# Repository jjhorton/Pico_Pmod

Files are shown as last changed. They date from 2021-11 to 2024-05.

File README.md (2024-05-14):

The aim of this repo is to have a PCB on which I was able to mount a standard
[Raspberry Pi Pico](https://www.raspberrypi.org/products/raspberry-pi-pico/) and have an extended duel PMod Connector. This would allow me to connect up the Raspberry Pi Pico upto a range of PMod Boards that I already own, as well as to connect it upto some of the FPGA boards that I already own though there PMod connector.

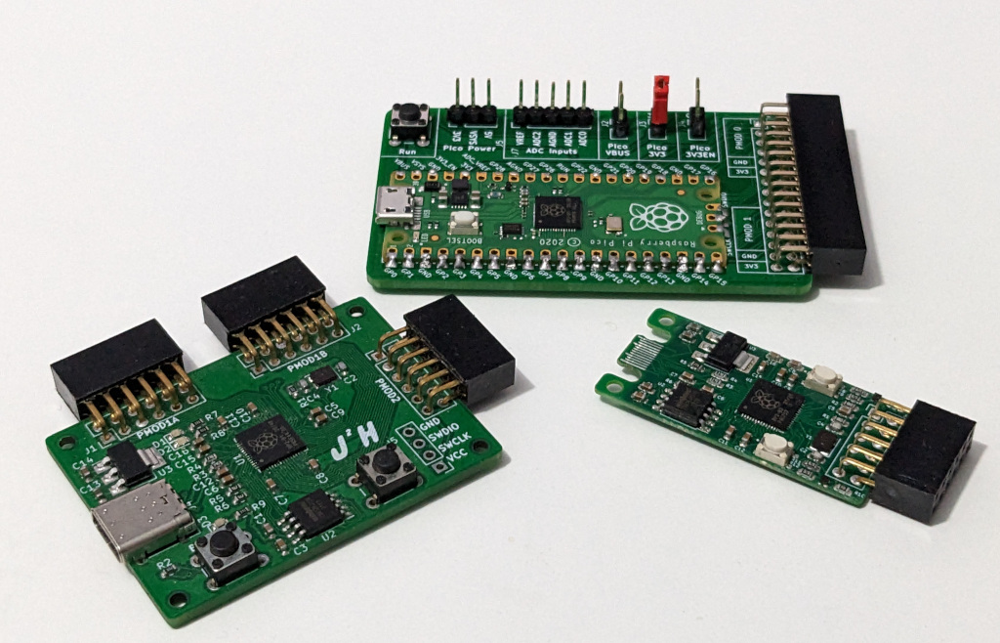
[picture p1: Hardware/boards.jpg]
All three PMod Boards


# Hardware

| Board | Build Status | Description |
| --- | --- | --- |
| [Pico PMod](https://kicanvas.org/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) |  | Raspberry Pi Pico Based PMod Breakout Board |
| [RP2040 PMod](https://kicanvas.org/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) |  | A PMod Board based on the RP2040 Chip |
| [RP2040 Mini PMod](https://kicanvas.org/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) |  | A mini Board with a single PMod connector and SD card reader |

For working with the pre existing PMod Boards I've made a PMod Host board,
this hosts the accessories such as an [Seven Segment display]() or
[PMOD buttons](). This allows me to work with boards I already have For
my FPGA development boards, and connect them up to the Pico.

The second board is designed to use the RP2040 chip directly, and create a small form factor PMod Board, this will use the RP2040 reference design, with a USB-C (2.0) Port, and 3 PMod Connectors that allow for PMod Devices to be connected up to the RP2040.

# Software

These are some examples that I have written to make use of the Host board with
my existing PMod accessories that I have around, these are two examples from Mouser which can be purchased, they are a [Seven Segment Display](https://www.mouser.co.uk/ProductDetail/1BitSquared/CS-ICEBREAKER-08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) and a [8 way switch](https://www.mouser.co.uk/ProductDetail/1BitSquared/CS-ICEBREAKER-07?qs=Cb2nCFKsA8ouK5JTufn3Bg%3D%3D). These simple examples can be found in the Software Folder, are written in `C` and require the Pico SDK to be able to build them.

These Software examples currently target only the board Pico Pmod Board, pins need to be changed for them to work with the RP2040 Board.

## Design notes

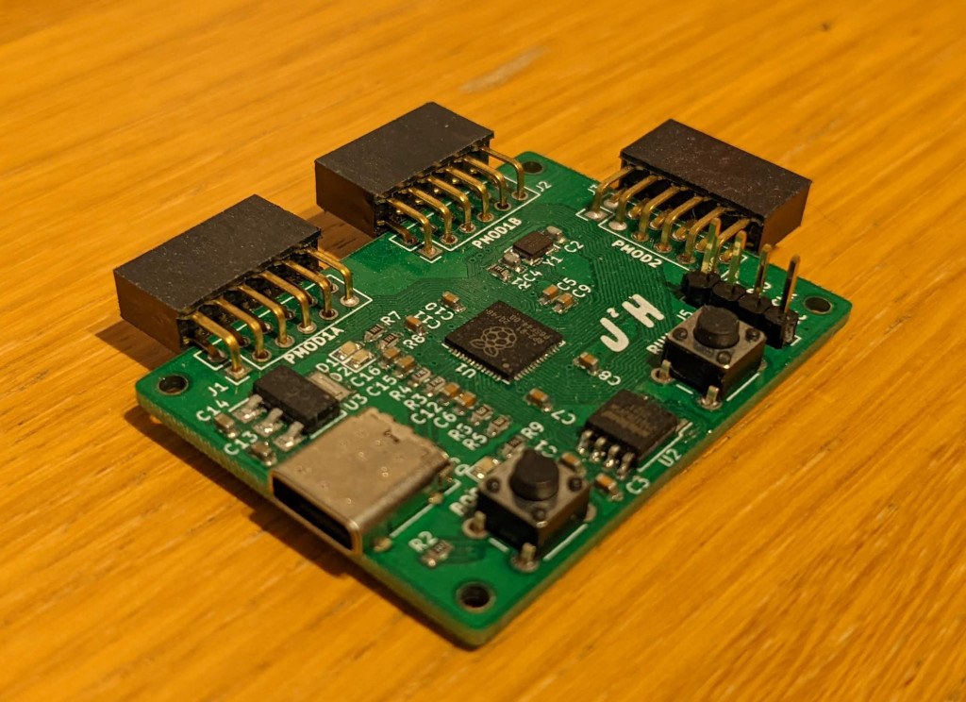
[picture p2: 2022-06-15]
Hardware/RP2040_PMod/board.jpg

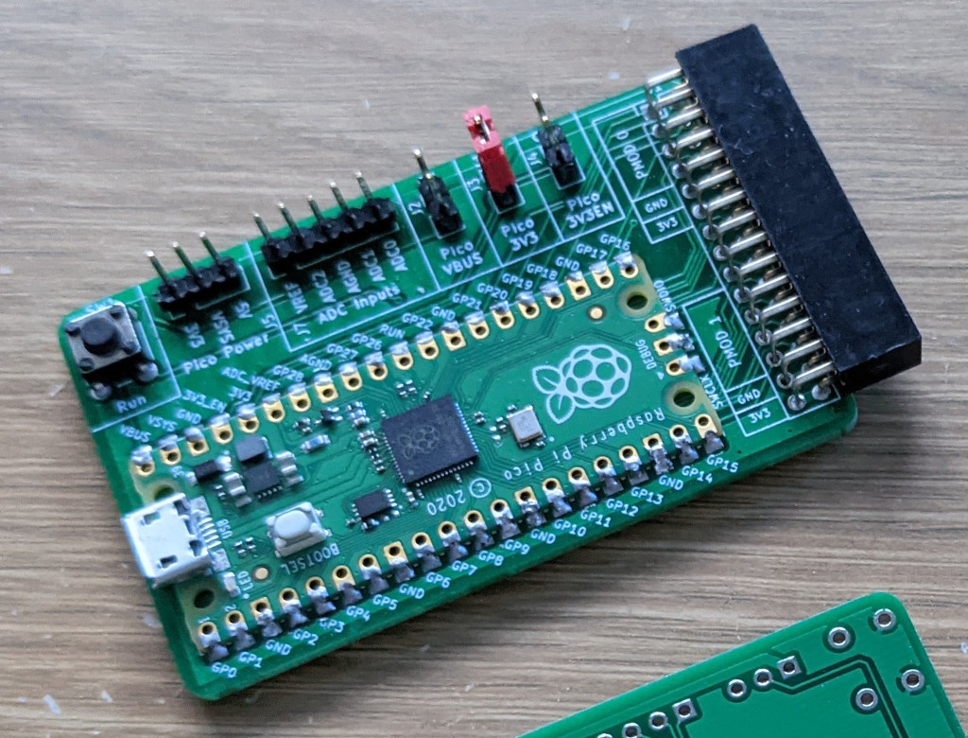
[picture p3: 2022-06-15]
Hardware/Pico_PMod/board.jpg

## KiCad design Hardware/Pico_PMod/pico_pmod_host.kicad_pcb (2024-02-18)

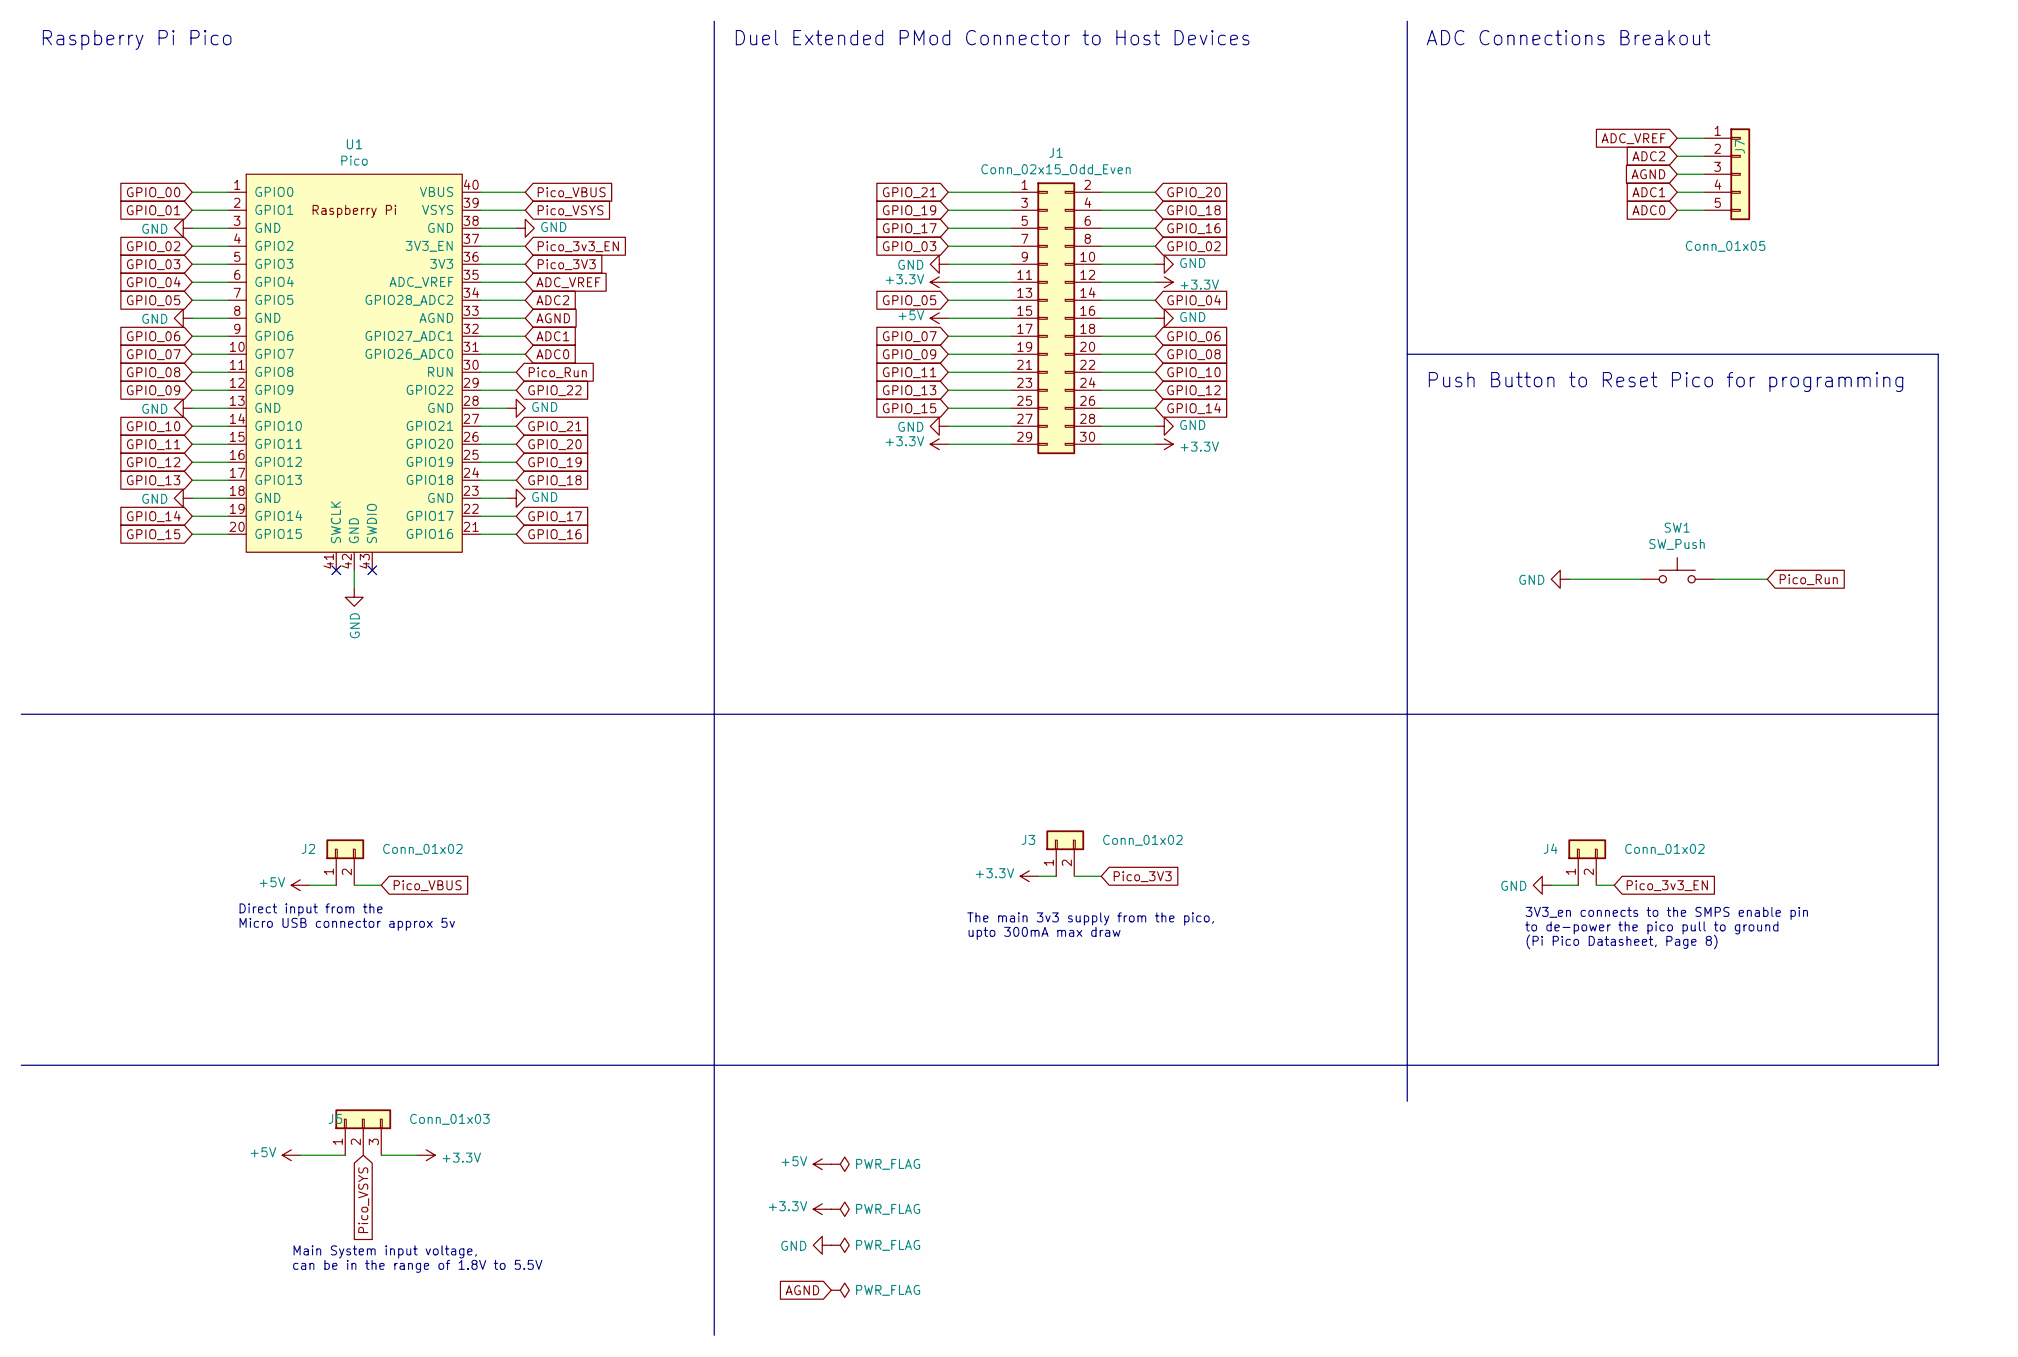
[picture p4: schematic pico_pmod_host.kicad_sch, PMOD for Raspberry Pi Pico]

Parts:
J1: Conn_02x15_Odd_Even; PinHeader_2x15_P2.54mm_Vertical
J2, J3, J4: Conn_01x02; PinHeader_1x02_P2.54mm_Vertical
J5: Conn_01x03; PinHeader_1x03_P2.54mm_Vertical
J7: Conn_01x05; PinHeader_1x05_P2.54mm_Vertical
SW1: SW_Push; SW_PUSH_6mm_H4.3mm
U1: Pico; RPi_Pico_SMD_TH

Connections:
+3V3: J1.11, J1.12, J1.29, J1.30, J3.1, J5.3
+5V: J1.15, J2.1, J5.1
ADC0: J7.5, U1.31 (GPIO26_ADC0)
ADC1: J7.4, U1.32 (GPIO27_ADC1)
ADC2: J7.2, U1.34 (GPIO28_ADC2)
ADC_VREF: J7.1, U1.35 (ADC_VREF)
AGND: J7.3, U1.33 (AGND)
GND: J1.9, J1.10, J1.16, J1.27, J1.28, J4.1, SW1.1, U1.3 (GND), U1.8 (GND), U1.13 (GND), U1.18 (GND), U1.23 (GND), U1.28 (GND), U1.38 (GND), U1.42 (GND)
GPIO_00: U1.1 (GPIO0)
GPIO_01: U1.2 (GPIO1)
GPIO_02: J1.8, U1.4 (GPIO2)
GPIO_03: J1.7, U1.5 (GPIO3)
GPIO_04: J1.14, U1.6 (GPIO4)
GPIO_05: J1.13, U1.7 (GPIO5)
GPIO_06: J1.18, U1.9 (GPIO6)
GPIO_07: J1.17, U1.10 (GPIO7)
GPIO_08: J1.20, U1.11 (GPIO8)
GPIO_09: J1.19, U1.12 (GPIO9)
GPIO_10: J1.22, U1.14 (GPIO10)
GPIO_11: J1.21, U1.15 (GPIO11)
GPIO_12: J1.24, U1.16 (GPIO12)
GPIO_13: J1.23, U1.17 (GPIO13)
GPIO_14: J1.26, U1.19 (GPIO14)
GPIO_15: J1.25, U1.20 (GPIO15)
GPIO_16: J1.6, U1.21 (GPIO16)
GPIO_17: J1.5, U1.22 (GPIO17)
GPIO_18: J1.4, U1.24 (GPIO18)
GPIO_19: J1.3, U1.25 (GPIO19)
GPIO_20: J1.2, U1.26 (GPIO20)
GPIO_21: J1.1, U1.27 (GPIO21)
GPIO_22: U1.29 (GPIO22)
Pico_3V3: J3.2, U1.36 (3V3)
Pico_3v3_EN: J4.2, U1.37 (3V3_EN)
Pico_Run: SW1.2, U1.30 (RUN)
Pico_VBUS: J2.2, U1.40 (VBUS)
Pico_VSYS: J5.2, U1.39 (VSYS)

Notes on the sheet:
Duel Extended PMod Connector to Host Devices
Main System input voltage, can be in the range of 1.8V to 5.5V
3V3_en connects to the SMPS enable pin to de-power the pico pull to ground (Pi Pico Datasheet, Page 8)
The main 3v3 supply from the pico, upto 300mA max draw
Push Button to Reset Pico for programming
ADC Connections Breakout
Direct input from the Micro USB connector approx 5v
Raspberry Pi Pico

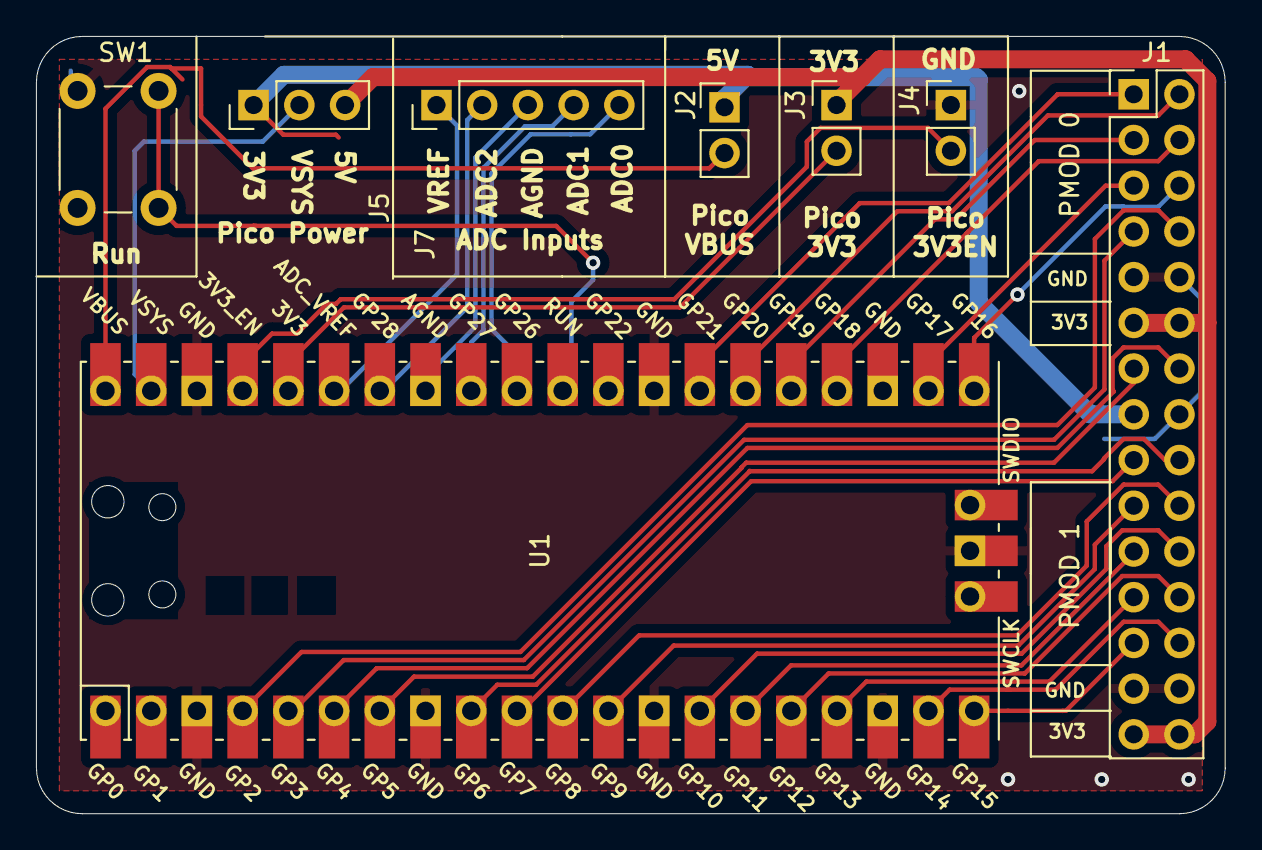
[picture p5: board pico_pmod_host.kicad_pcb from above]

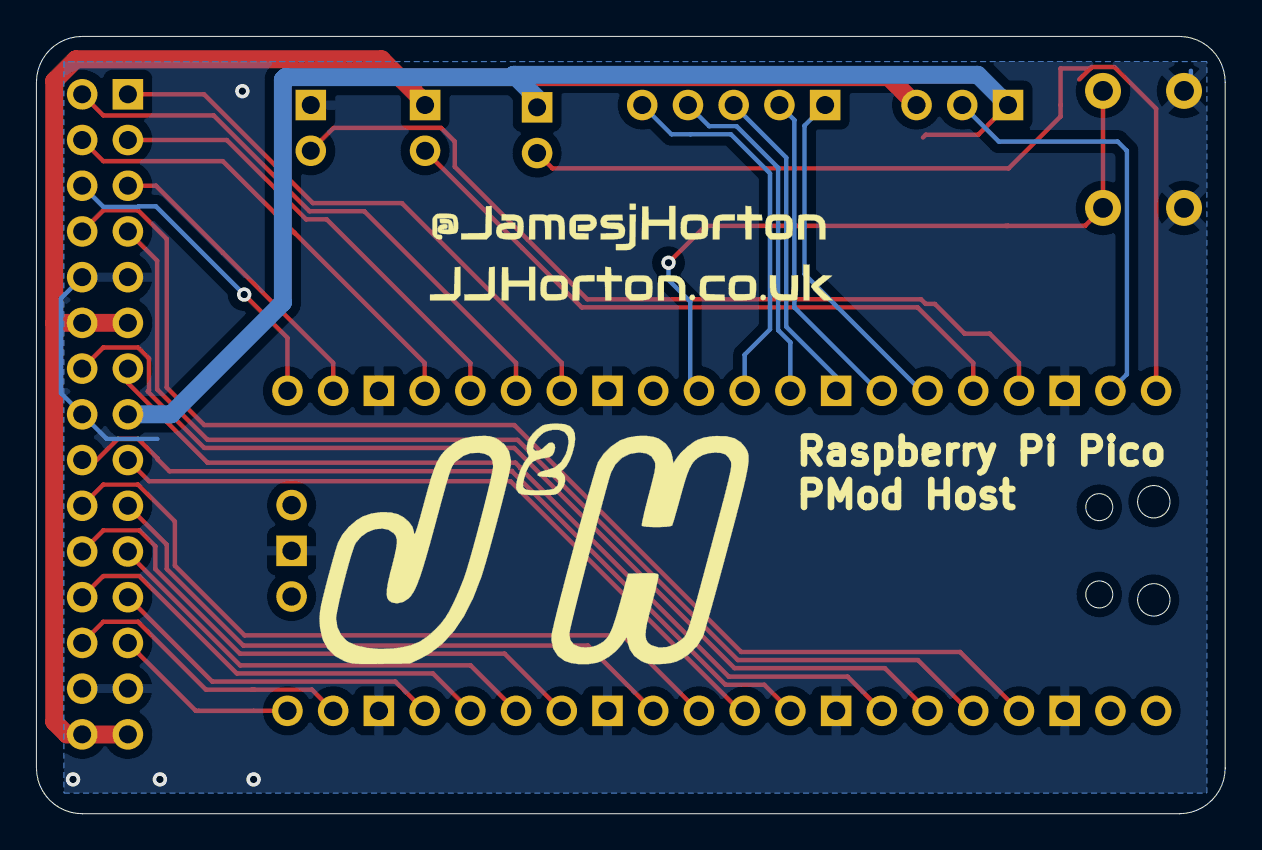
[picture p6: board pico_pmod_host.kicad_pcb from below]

Board: 2 copper layers, 66.0 x 43.2 mm, 10 parts (2 on the bottom side), 33 nets.

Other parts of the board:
Logo1: LOGO; Untitled
Logo2: LOGO; ContactDetails_small

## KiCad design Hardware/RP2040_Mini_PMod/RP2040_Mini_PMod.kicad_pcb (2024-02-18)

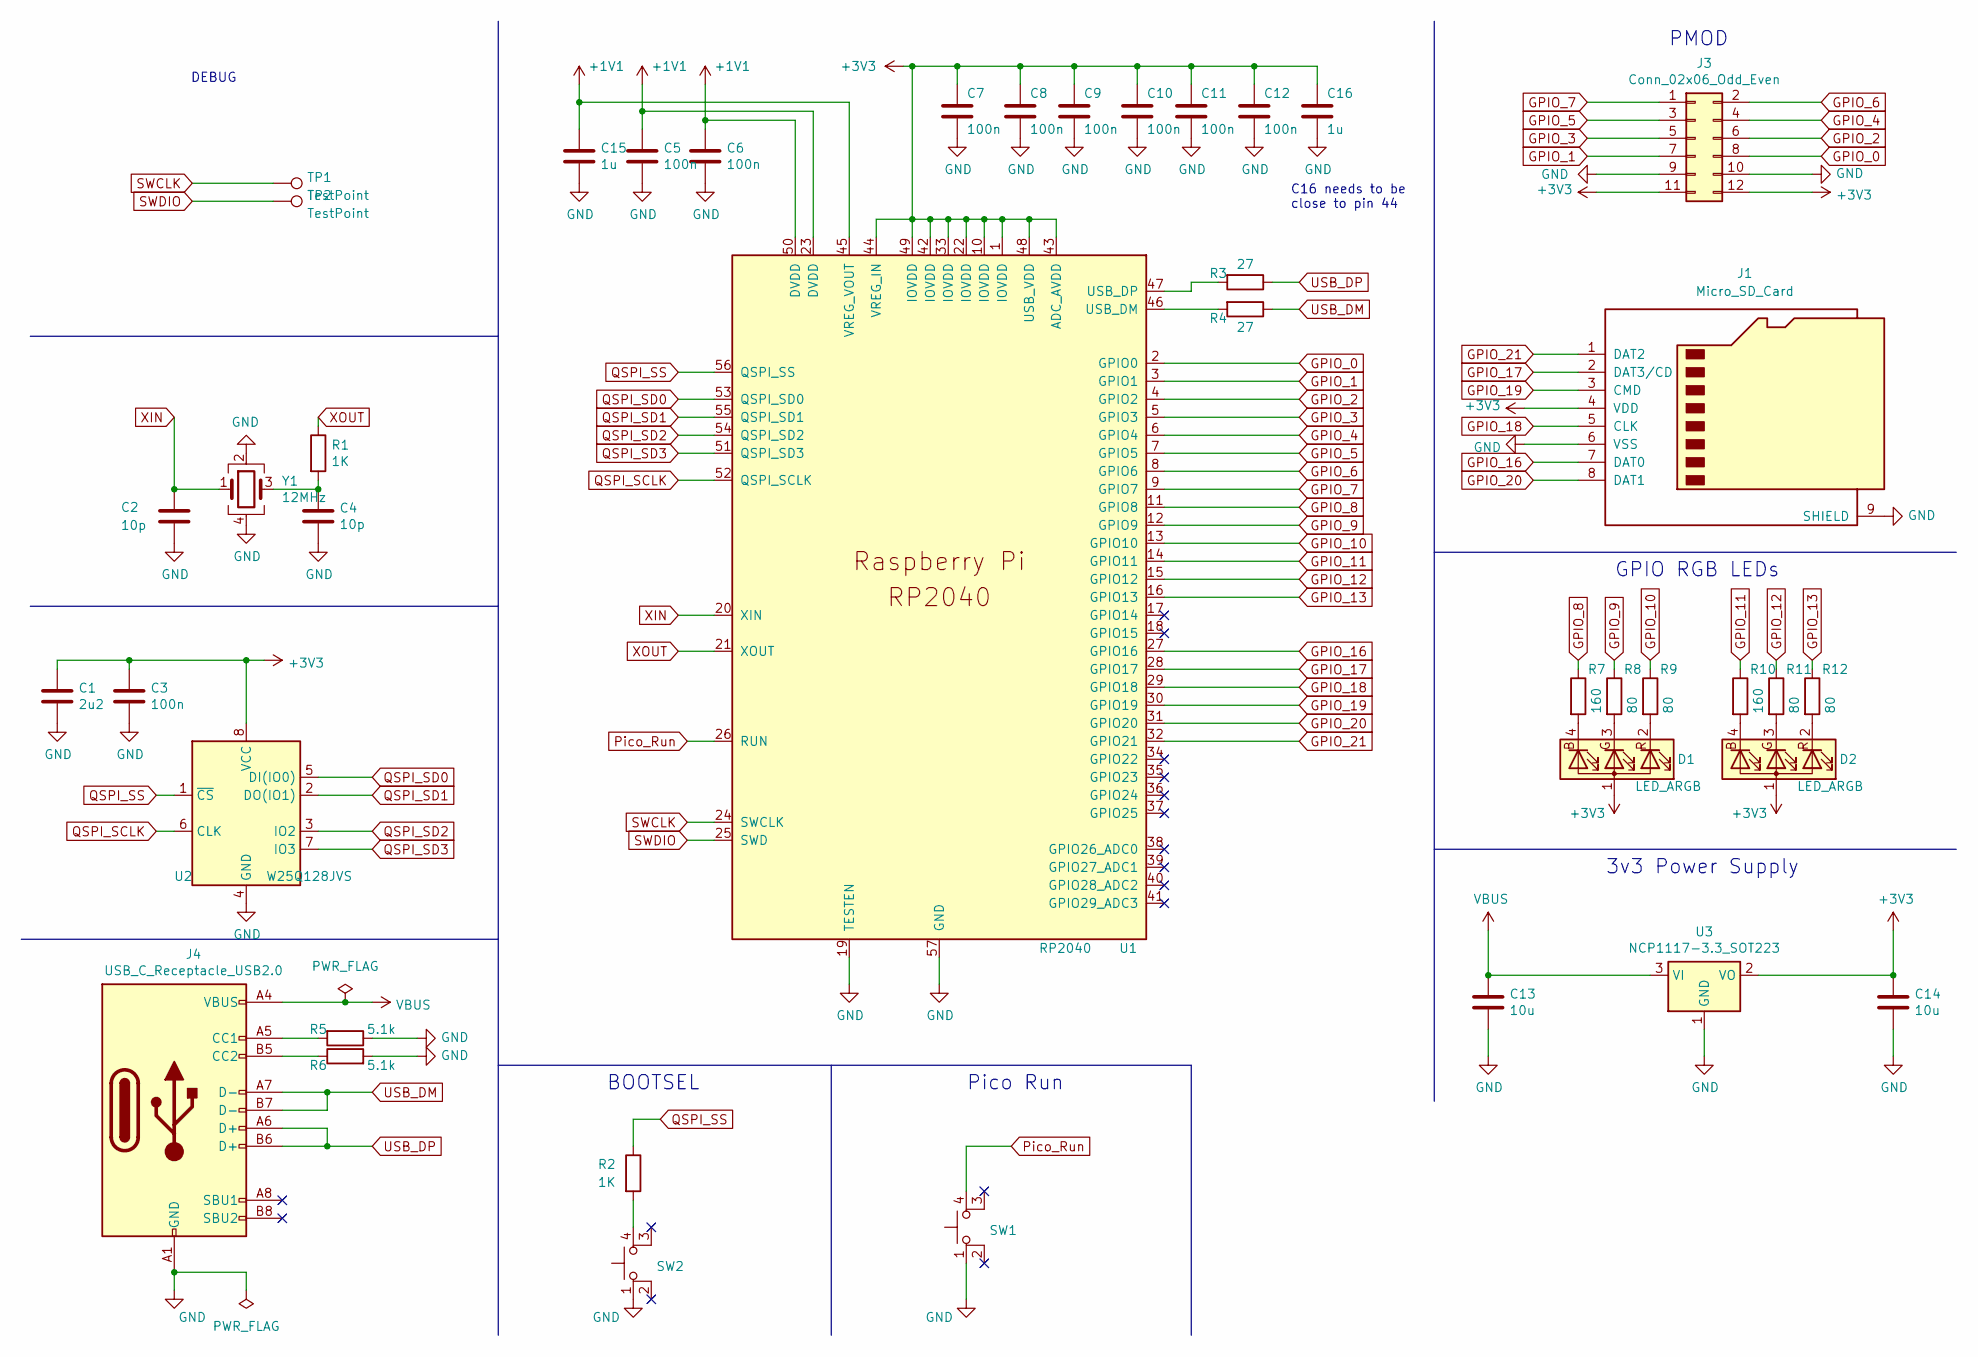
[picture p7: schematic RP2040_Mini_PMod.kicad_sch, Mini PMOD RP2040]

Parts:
C1: 2u2; C_0603_1608Metric
C2, C4: 10p; C_0603_1608Metric
C3, C5, C6, C7, C8, C9, C10, C11, C12: 100n; C_0603_1608Metric
C13, C14: 10u; C_0603_1608Metric
C15, C16: 1u; C_0603_1608Metric
D1, D2: LED_ARGB; SX-0402-RGB
J1: Micro_SD_Card; 105162-0001
J3: Conn_02x06_Odd_Even; PinHeader_2x06_P2.54mm_Vertical
J4: USB_C_Receptacle_USB2.0; USB-C-PCB
R1, R2: 1K; R_0603_1608Metric
R3, R4: 27; R_0603_1608Metric
R5, R6: 5.1k; R_0603_1608Metric
R7, R10: 160; R_0603_1608Metric
R8, R9, R11, R12: 80; R_0603_1608Metric
SW1, SW2: PTS815 SJK 250 SMTR LFS; PTS815SJK250SMTRLFS
TP1, TP2: TestPoint; TestPoint_Pad_D1.5mm
U1: RP2040; RP2040-QFN-56
U2: W25Q128JVS; SOIC-8_5.23x5.23mm_P1.27mm
U3: NCP1117-3.3_SOT223; SOT-223-3_TabPin2
Y1: 12MHz; Crystal_SMD_SeikoEpson_FA238-4Pin_3.2x2.5mm

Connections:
+1V1: C5.1, C6.1, C15.1, U1.23 (DVDD), U1.45 (VREG_VOUT), U1.50 (DVDD)
+3V3: C1.1, C3.1, C7.1, C8.1, C9.1, C10.1, C11.1, C12.1, C14.1, C16.1, D1.1 (A), D2.1 (A), J1.4 (VDD), J3.11, J3.12, U1.1 (IOVDD), U1.10 (IOVDD), U1.22 (IOVDD), U1.33 (IOVDD), U1.42 (IOVDD), U1.43 (ADC_AVDD), U1.44 (VREG_IN), U1.48 (USB_VDD), U1.49 (IOVDD), U2.8 (VCC), U3.2 (VO)
GND: C1.2, C2.2, C3.2, C4.2, C5.2, C6.2, C7.2, C8.2, C9.2, C10.2, C11.2, C12.2, C13.2, C14.2, C15.2, C16.2, J1.6 (VSS), J1.9 (SHIELD), J3.9, J3.10, J4.A1 (GND), J4.A12 (GND), J4.B1 (GND), J4.B12 (GND), R5.1, R6.2, SW1.1, SW2.1, U1.19 (TESTEN), U1.57 (GND), U2.4 (GND), U3.1 (GND), Y1.2, Y1.4
GPIO_0: J3.8, U1.2 (GPIO0)
GPIO_1: J3.7, U1.3 (GPIO1)
GPIO_2: J3.6, U1.4 (GPIO2)
GPIO_3: J3.5, U1.5 (GPIO3)
GPIO_4: J3.4, U1.6 (GPIO4)
GPIO_5: J3.3, U1.7 (GPIO5)
GPIO_6: J3.2, U1.8 (GPIO6)
GPIO_7: J3.1, U1.9 (GPIO7)
GPIO_8: R7.1, U1.11 (GPIO8)
GPIO_9: R8.1, U1.12 (GPIO9)
GPIO_10: R9.1, U1.13 (GPIO10)
GPIO_11: R10.1, U1.14 (GPIO11)
GPIO_12: R11.1, U1.15 (GPIO12)
GPIO_13: R12.1, U1.16 (GPIO13)
GPIO_16: J1.7 (DAT0), U1.27 (GPIO16)
GPIO_17: J1.2 (DAT3/CD), U1.28 (GPIO17)
GPIO_18: J1.5 (CLK), U1.29 (GPIO18)
GPIO_19: J1.3 (CMD), U1.30 (GPIO19)
GPIO_20: J1.8 (DAT1), U1.31 (GPIO20)
GPIO_21: J1.1 (DAT2), U1.32 (GPIO21)
unnamed: C4.1, R1.2, Y1.3
unnamed: D1.4 (BK), R7.2
unnamed: D1.3 (GK), R8.2
unnamed: D1.2 (RK), R9.2
unnamed: D2.4 (BK), R10.2
unnamed: D2.3 (GK), R11.2
unnamed: D2.2 (RK), R12.2
unnamed: J4.A5 (CC1), R5.2
unnamed: J4.B5 (CC2), R6.1
unnamed: R2.2, SW2.4 (A)
unnamed: R4.2, U1.46 (USB_DM)
unnamed: R3.2, U1.47 (USB_DP)
Pico_Run: SW1.4 (A), U1.26 (RUN)
QSPI_SCLK: U1.52 (QSPI_SCLK), U2.6 (CLK)
QSPI_SD0: U1.53 (QSPI_SD0), U2.5 (DI(IO0))
QSPI_SD1: U1.55 (QSPI_SD1), U2.2 (DO(IO1))
QSPI_SD2: U1.54 (QSPI_SD2), U2.3 (IO2)
QSPI_SD3: U1.51 (QSPI_SD3), U2.7 (IO3)
QSPI_SS: R2.1, U1.56 (QSPI_SS), U2.1 (~CS)
SWCLK: TP1.1, U1.24 (SWCLK)
SWDIO: TP2.1, U1.25 (SWD)
USB_DM: J4.A7 (D-), J4.B7 (D-), R4.1
USB_DP: J4.A6 (D+), J4.B6 (D+), R3.1
VBUS: C13.1, J4.A4 (VBUS), J4.A9 (VBUS), J4.B4 (VBUS), J4.B9 (VBUS), U3.3 (VI)
XIN: C2.1, U1.20 (XIN), Y1.1
XOUT: R1.1, U1.21 (XOUT)

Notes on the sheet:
Pico Run
DEBUG
GPIO RGB LEDs
3v3 Power Supply
PMOD
BOOTSEL
C16 needs to be close to pin 44

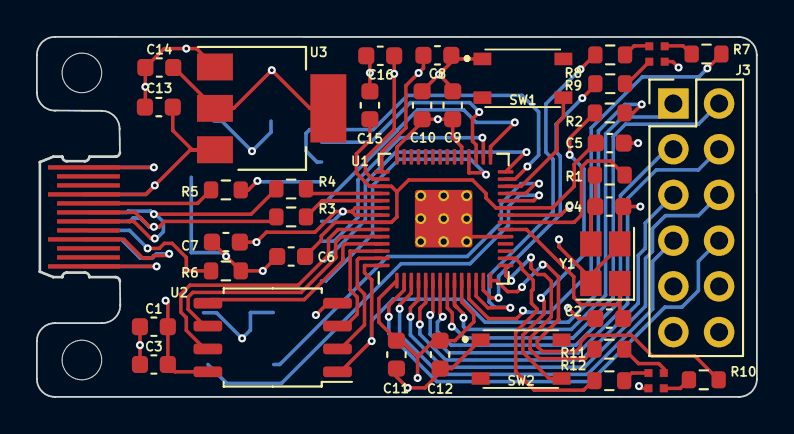
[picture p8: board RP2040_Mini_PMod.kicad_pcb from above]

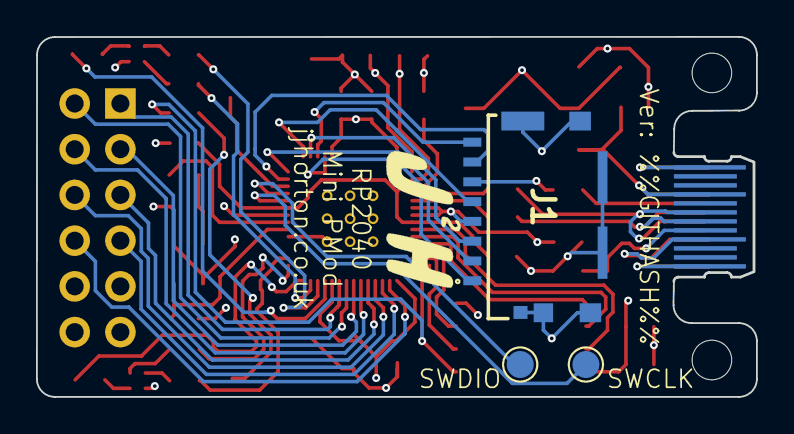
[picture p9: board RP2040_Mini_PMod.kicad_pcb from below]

Board: 4 copper layers, 40.0 x 20.0 mm, 44 parts (4 on the bottom side), 49 nets.

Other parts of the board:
G1: LOGO; j2h_small
Mount1, Mount1#2: MountingHole_2.2mm_M2

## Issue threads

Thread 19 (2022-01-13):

Add photos of the boards in README

jjhorton, 2022-01-13:
Add 2 photos to the repo, one of each board

- [ ] RP2040 PMOD
- [ ] Pico PMod Board

jjhorton, 2022-06-15:
solved by #26

Closed 2022-06-15.

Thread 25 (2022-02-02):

Upgrade the Pico Pmod Board to kicad 6.0

jjhorton, 2022-02-02:
The RP Pico PMod Board kicad files need to be upgraded to kicad 6.0 to ensure the versions match

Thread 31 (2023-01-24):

RGB LED Not working on RP2040_Mini_PMod

jjhorton, 2023-01-24:

jjhorton, 2023-01-24:
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

LED polarity is incorrect, pin 1 is connected to GND but should be to 3v3

Closed 2023-02-06.

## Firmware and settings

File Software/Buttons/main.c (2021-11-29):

/**
 * Copyright (c) 2021 James Horton.
 * SPDX-License-Identifier: BSD-3-Clause
 */

#include "pico/stdlib.h"

#define LOOKUP_TABLE_LENGTH 100


int main() {
		//const uint SEVEN_SEGMENT_PINS[] = {9,10,13,15,8,11,12,14};
		//const uint SEVEN_SEGMENT_PINS[] = {12,11,8,15,13,10,9,14};
		const uint SEVEN_SEGMENT_PINS[] = {9,11,13,15,8,10,12,14};
		//const uint BUTTON_PINS[] = {2,3,18,19,16,17,20,21};
		const uint BUTTON_PINS[] = {2,16,18,20,3,17,19,21};
		const uint CLK_PIN = 9;

		uint8_t lookup_table[LOOKUP_TABLE_LENGTH];

		for(int x; x<LOOKUP_TABLE_LENGTH; x++){
			lookup_table[x] = LOOKUP_TABLE_LENGTH-x;
		}

		// The output to the system
		for(int x = 0; x<8; x++) {
				gpio_init(SEVEN_SEGMENT_PINS[x]);
				gpio_set_dir(SEVEN_SEGMENT_PINS[x], GPIO_OUT);
				gpio_put(SEVEN_SEGMENT_PINS[x],0);
		}

		// Set the pins to input
		for(int x = 0; x<8; x++) {
				gpio_init(BUTTON_PINS[x]);
				gpio_set_dir(BUTTON_PINS[x], GPIO_IN);
		}

		uint8_t temp = 0b0000000;
		uint counter = 0;
		uint8_t input1 = 0;
		uint8_t input2 = 0;

		uint8_t characters[] = {0b01000000,	// 0
														0b01111001,	// 1
														0b00100100,	// 2
														0b00110000,	// 3
														0b00011001,	// 4
														0b00010010,	// 5
														0b00000010,	// 6
														0b01111000,	// 7
														0b00000000,	// 8
														0b00011000,	// 9
														0b00001000,	// A
														0b00000011,	// B
														0b01000110,	// C
														0b00100001,	// D
														0b00000110,	// E
														0b00001110};// F

		while (true) {

			// Read the values from the buttons
			input1 = 0;
			for(int x = 0; x<4; x++) {
				input1 = (gpio_get(BUTTON_PINS[x])<<x) + input1;
			}
			input2 = 0;
			for(int x = 0; x<4; x++) {
				input2 = (gpio_get(BUTTON_PINS[x+4])<<x) + input2;
			}

			//for the first digit
			for(int x = 0; x<7; x++) {
        gpio_put(SEVEN_SEGMENT_PINS[x], (characters[input1] >> x) & 1U);
			}

			gpio_put(SEVEN_SEGMENT_PINS[7], 1);
			sleep_ms(10);

			//for the second digit
			for(int x = 0; x<7; x++) {
				gpio_put(SEVEN_SEGMENT_PINS[x], (characters[input2] >> x) & 1U);
			}

			gpio_put(SEVEN_SEGMENT_PINS[7], 0);
			sleep_ms(10);

    }
}

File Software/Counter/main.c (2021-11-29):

/**
 * Copyright (c) 2021 James Horton.
 * SPDX-License-Identifier: BSD-3-Clause
 */

#include "pico/stdlib.h"

#define LCD_DISPLAY 1
#define LOOKUP_TABLE_LENGTH 50

#if (LCD_DISPLAY==0)
	//if plugged into pmod1
	const uint SEVEN_SEGMENT_PINS[] = {9,11,13,15,8,10,12,14};
#else
	//if plugged into pmod0
	const uint SEVEN_SEGMENT_PINS[] = {21,19,17,3,20,18,16,2};
#endif

int setup_display(){
	for(int x = 0; x<8; x++) {
			gpio_init(SEVEN_SEGMENT_PINS[x]);
			gpio_set_dir(SEVEN_SEGMENT_PINS[x], GPIO_OUT);
			gpio_put(SEVEN_SEGMENT_PINS[x],0);
	}
}

int set_display(uint num1, uint num2){

	// the table used to set the charcter to be on
	uint8_t characters[] = {0b01000000,	// 0
													0b01111001,	// 1
													0b00100100,	// 2
													0b00110000,	// 3
													0b00011001,	// 4
													0b00010010,	// 5
													0b00000010,	// 6
													0b01111000,	// 7
													0b00000000,	// 8
													0b00011000,	// 9
													0b00001000,	// A
													0b00000011,	// B
													0b01000110,	// C
													0b00100001,	// D
													0b00000110,	// E
													0b00001110};// F


	// set the display values
	//for the first digit
	for(int x = 0; x<7; x++) {
		gpio_put(SEVEN_SEGMENT_PINS[x], (characters[num1] >> x) & 1U);
	}

	gpio_put(SEVEN_SEGMENT_PINS[7], 1);
	sleep_ms(10);

	//for the second digit
	for(int x = 0; x<7; x++) {
		gpio_put(SEVEN_SEGMENT_PINS[x], (characters[num2] >> x) & 1U);
	}

	gpio_put(SEVEN_SEGMENT_PINS[7], 0);
	sleep_ms(10);

	return 0;
}

int main() {

		// setup the outputs for the display
		setup_display();

		//initalise the counters used to count up on the display

		uint counter = 0;
		uint counter1 = 0;
		uint counter2 = 0;

		// main loop for updating the display and updating the counter
		while (true) {
			set_display(counter1, counter2);
			counter++;

			if(counter>PAUSE_LENGTH){ counter = 0; counter1++;}
			if(counter1>15){ counter1=0; counter2++;}
			if(counter2>15){ counter2=0;}
    }
}

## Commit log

2021-04-15 inital commit of schematic and board
    [pico_pmod.kicad_pcb, pico_pmod.sch]
2021-04-15 add power pin headers and initial layout work
    [pico_pmod.kicad_pcb, pico_pmod.sch]
2021-04-15 finish layout, start of silk screen
    [pico_pmod.kicad_pcb, pico_pmod.sch]
2021-04-16 sort out keepout areas for ground plane on board top
    [pico_pmod.kicad_pcb]
2021-04-16 breakout ADC inputs to pins
    [pico_pmod.kicad_pcb, pico_pmod.sch]
2021-04-16 minor silkscreen changes before ordering
    [pico_pmod.kicad_pcb]
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2021-04-21 Add PDF version of the Schematic to the repo
    [pico_pmod.sch]
2021-04-22 Add Reset button to the Pico Schematic
    [pico_pmod.sch]
2021-04-22 Add Run switch to the PCB
    [pico_pmod.kicad_pcb]
2021-04-22 Remove Run Header pins
    [pico_pmod.kicad_pcb, pico_pmod.sch]
2021-04-22 move existing design to client folder
    [pico_pmod.kicad_pcb, pico_pmod.sch]
2021-04-22 create files for the host version
    [pico_pmod_host.kicad_pcb, pico_pmod_host.sch]
2021-04-22 rotate the connector to match the pmod pins when hosting
    [pico_pmod_host.sch]
2021-04-22 PMOD connector corrected to match schematic
    [pico_pmod_host.kicad_pcb]
2021-04-29 Minor changes to both PCB layouts
    [pico_pmod.kicad_pcb, pico_pmod_host.kicad_pcb]
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2021-05-03 reorder the buttons into the correct order
    [main.c]
2021-05-03 correct the button pin mappings
    [main.c]
2021-05-03 update the 5v pinout on the pmod connector for #1 on the host board
    [pico_pmod_host.sch]
2021-05-03 update the 5v pinout on the pmod connector for #1 on the PCB
    [pico_pmod_host.kicad_pcb]
2021-05-04 Change the logo on the host board
    [pico_pmod_host.kicad_pcb]
2021-05-10 Correct an error in the hash define
    [main.c]
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2021-06-08 correct the sch and pcb file names
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2021-07-09 initial schematic work for custom Pmod Board
    [pico_pmod.kicad_pcb, pico_pmod.sch]
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2021-07-12 initial functional PCB layout
    [pico_pmod.kicad_pcb, pico_pmod.sch]
2021-07-12 Add the switchs footprints and put on PCB
    [pico_pmod.kicad_pcb, pico_pmod.sch]
2021-07-12 Add usb CC 1 and 2 resistors
    [pico_pmod.kicad_pcb, pico_pmod.sch]
2021-07-13 Add power supply and spi memory
    [pico_pmod.kicad_pcb, pico_pmod.sch]
2021-07-13 Add the USB resitors and route power supply
    [pico_pmod.kicad_pcb, pico_pmod.sch]
2021-07-13 Add the debug port footprint
    [pico_pmod.kicad_pcb, pico_pmod.sch]
2021-07-14 PCB layout for PMOD1B and PMOD2
    [pico_pmod.kicad_pcb, pico_pmod.sch]
2021-07-14 Make headers virtual parts so they are not in 3D step models
    [pico_pmod.kicad_pcb]
2021-07-16 Add connections to PMOD1A connector
    [pico_pmod.kicad_pcb, pico_pmod.sch]
2021-07-16 update with ground plane and LED's
    [pico_pmod.kicad_pcb, pico_pmod.sch]
2021-07-16 Add the logo and text onto back of the PCB
    [pico_pmod.kicad_pcb]
2021-07-16 Add lables to the Debug Port
    [pico_pmod.kicad_pcb, pico_pmod.sch]
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2021-07-16 mark unused pins as not connected
    [pico_pmod.sch]
2021-07-16 fix DRC errors with 3v3 power
    [pico_pmod.kicad_pcb]
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2021-07-16 Ensure that pins 48 and 49 are connected to 3v3
    [pico_pmod.kicad_pcb]
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2021-07-16 update resistor values from schimatic
    [pico_pmod.kicad_pcb]
2021-08-05 Correct USB DP and DN for #7
    [pico_pmod.sch]
2021-08-05 Correct USB DP and DN on PCB for #7
    [pico_pmod.kicad_pcb]
2021-08-06 Add logo on front of board and straight PMod tracks
    [pico_pmod.kicad_pcb]
2021-08-11 edit the PMOD traces to straighten them
    [pico_pmod.kicad_pcb]
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2021-08-17 Rename the Custom PMod Board
    [pico_pmod.kicad_pcb, pico_pmod.sch]
2021-08-17 remove Client and rename Host to Pico PMod
    [pico_pmod.kicad_pcb, pico_pmod.sch, pico_pmod_host.kicad_pcb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]
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2021-08-28 Fix the Pmod RP2040 board workflow
2021-11-24 Update the clk Caps
    [pico_pmod.sch]
2021-11-30 Update with the license statement
    [pico_pmod_host.sch]
2021-11-30 Add descipriotn to the PCB Boards
    [pico_pmod.sch, pico_pmod_host.sch]
2021-11-30 Update the title for the RP2040 PCB Board
    [pico_pmod.sch]
2021-11-30 Add descriptions and titles to the PCB sheets
    [pico_pmod.kicad_pcb, pico_pmod_host.kicad_pcb]
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2022-01-25 update to kicad 6.0
    [pico_pmod.kicad_pcb, pico_pmod.kicad_sch, pico_pmod.sch]
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2022-01-25 correct kicad schematic file name
2022-01-25 add power flags to schematic for ERC
    [pico_pmod.kicad_sch]
2022-01-25 reroute usb-c (j4) gnd to avoid DRC issue
    [pico_pmod.kicad_pcb]
2022-01-25 Correct DRC warning for unconnected tracks and overlapping silkscreen
    [pico_pmod.kicad_pcb]
2022-01-25 Swap pin header 3d model for pin socket models
    [pico_pmod.kicad_pcb]
2022-01-26 Update the paths to 3d models to use a referencet to own library
    [pico_pmod.kicad_pcb]
2022-02-02 update 3D parts to use my custom models
    [pico_pmod.kicad_pcb]
2022-02-02 correct scaling for the rp2040
    [pico_pmod.kicad_pcb]
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2023-01-03 add initial attempt at mini board
    [RP2040_Mini_PMod.kicad_pcb, RP2040_Mini_PMod.kicad_sch]
2023-01-03 continue with mini project
    [RP2040_Mini_PMod.kicad_pcb, RP2040_Mini_PMod.kicad_sch]
2023-01-03 Add the SD GPIO and RGB LED to schematic
    [RP2040_Mini_PMod.kicad_pcb, RP2040_Mini_PMod.kicad_sch]
2023-01-04 complete schematic and start pcb routing
    [RP2040_Mini_PMod.kicad_pcb, RP2040_Mini_PMod.kicad_sch]
2023-01-04 update switch layout and sd card gnd pins
    [RP2040_Mini_PMod.kicad_pcb, RP2040_Mini_PMod.kicad_sch]
2023-01-05 remove usb sheild from usb connector
    [RP2040_Mini_PMod.kicad_sch]
2023-01-05 update button footprint and fix some drc errors
    [RP2040_Mini_PMod.kicad_pcb]
2023-01-05 update the 3d models for switches
    [RP2040_Mini_PMod.kicad_pcb]
2023-01-05 replace 3d model for RP2040 and add 3d model for rgb LEDs
    [RP2040_Mini_PMod.kicad_pcb]
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2023-01-06 add githash to back of PCB
    [RP2040_Mini_PMod.kicad_pcb]
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2023-01-10 increase the space around the usb-c corrector
    [RP2040_Mini_PMod.kicad_pcb]
2023-01-10 fix uneven sides of the usb connector
    [RP2040_Mini_PMod.kicad_pcb]
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2023-02-06 correct 3v3 issue for #31 with LED's
    [RP2040_Mini_PMod.kicad_sch]
2023-02-06 include the correction on the pcb layout
    [RP2040_Mini_PMod.kicad_pcb]
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2024-02-17 upgrade to kicad 7.0
    [RP2040_Mini_PMod.kicad_pcb, RP2040_Mini_PMod.kicad_sch]
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2024-02-17 Change reference for error
    [RP2040_Mini_PMod.kicad_pcb]
2024-02-17 change reference for logo
    [RP2040_Mini_PMod.kicad_pcb]
2024-02-17 change REF to Mount
    [RP2040_Mini_PMod.kicad_pcb]
2024-02-18 Update schematic to kicad7
    [pico_pmod.kicad_sch]
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

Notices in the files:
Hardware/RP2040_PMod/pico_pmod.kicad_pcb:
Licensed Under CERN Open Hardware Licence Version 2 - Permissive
